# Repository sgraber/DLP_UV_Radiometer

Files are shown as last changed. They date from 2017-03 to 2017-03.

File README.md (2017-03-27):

# DLP_UV_Radiometer

This is a very simple, low cost, bare bones DLP UV Radiometer that measures the UV output of a DLP projector in mW/cm^2.  It is a useful tool for any DLP UV resin printer as it helps by measuring the UV output and by knowing your UV output and the Critical Energy required to properly cure a UV resin, the end user can calculate how many seconds exposure he or she will need.

MakerJuice MakerJuice Labs

I developed this with the initial intent to use it to characterize [MakerJuice UV Resins](http://www.makerjuice.com/) and decided it might be prudent to allow others to build this too and expand on it.  If expanding on this project, please credit both MakerJuice Labs and myself.  :)

Many UV resin manufacturers supply the Critical Energy required to properly cure their resins at a given layer height.  This number is typically supplied in mJ/cm^2.  If the end user knows their DLP UV output in mW/cm^2, they can simply apply the following forumla to find out how many seconds exposure they will need for their particular setup:

Seconds Exposure = (mJ/cm^2) / (mW/cm^2)

Then simply set your layer height and exposure time and the end user should be in the ballpark (or closer) for their exposure time.

As written, the sensor is wired up to an Arduino Nano, which is in turn plugged into either a computer or a smartphone with a USB-OTG cable.  To use it, simply place the sensor at the appropriate distance from the DLP light source and either use the Ardino IDI serial terminal to obtain the output reading or plug it into your smartphone using a USB-OTG cable and run something like DroidTerm to view your results.

# Hookup Guide

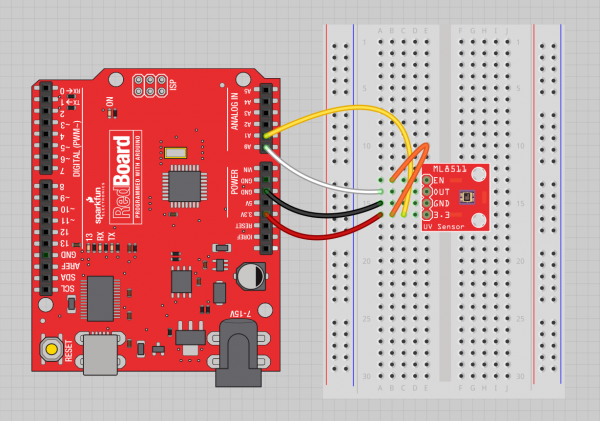
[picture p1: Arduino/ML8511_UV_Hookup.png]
Wiring Sparkfun Redboard and ML8511 Sensor


# Development Links

http://makerhive.proboards.com/thread/641/low-cost-uv-radiometer

https://learn.sparkfun.com/tutorials/ml8511-uv-sensor-hookup-guide

http://makerhive.proboards.com/thread/1045/help-circuit-schematic

https://goo.gl/photos/gHvPpna38RmeMD9JA

https://goo.gl/photos/hdz6ypwXF4V1uDZu9

https://goo.gl/photos/mLwZ4yQtefcNKiSG6

# License

CC-SA (see cc-sa-license.txt)

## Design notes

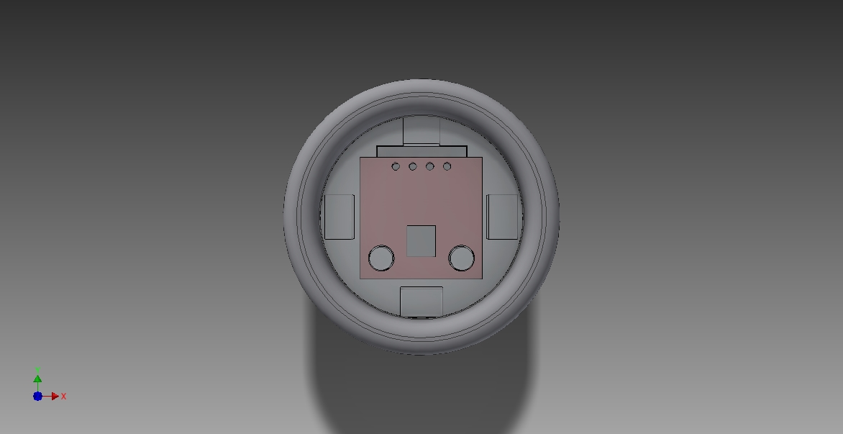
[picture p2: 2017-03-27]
STLs/UV Sensor2.jpg

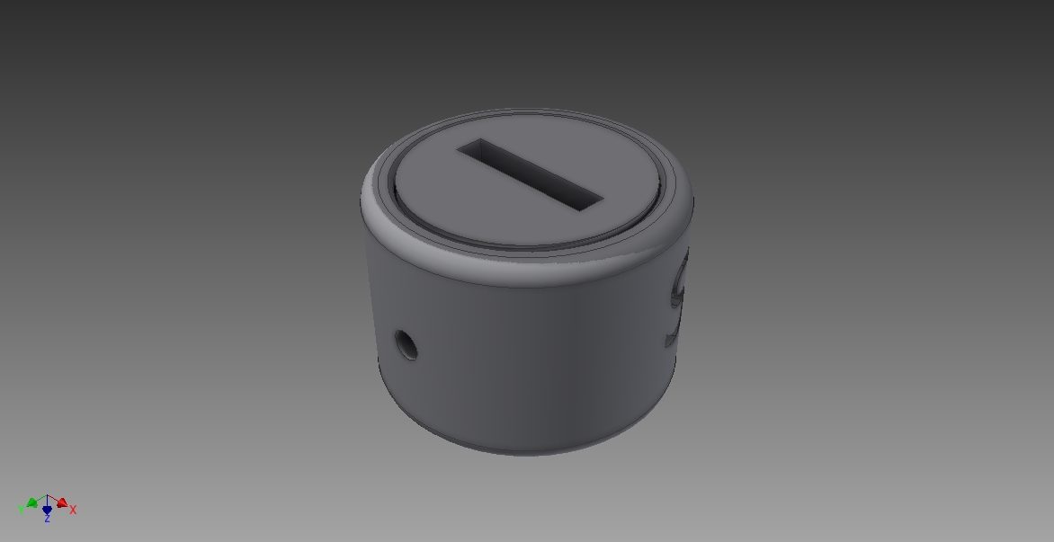
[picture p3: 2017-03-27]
STLs/UV Sensor3.jpg

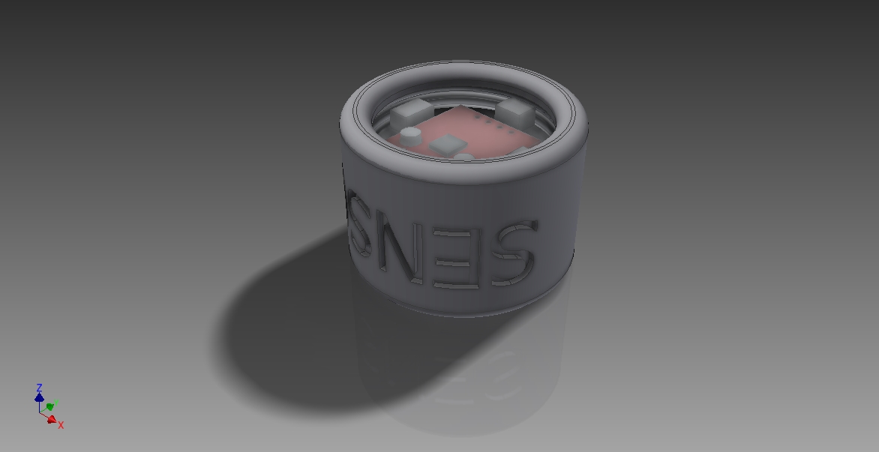
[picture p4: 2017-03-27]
STLs/UV Sensor.jpg

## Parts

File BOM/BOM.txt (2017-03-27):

Arduino Nano:  
	Any Nano clone will do.

UV Sensor:  SparkFun UV Sensor Breakout - ML8511
	Sparkfun:  https://www.sparkfun.com/products/12705
	Aliexpress:  Search for ML8511
	Ebay:  Search for ML8511

Telephone or Ethernet cable / wire:  18 inches

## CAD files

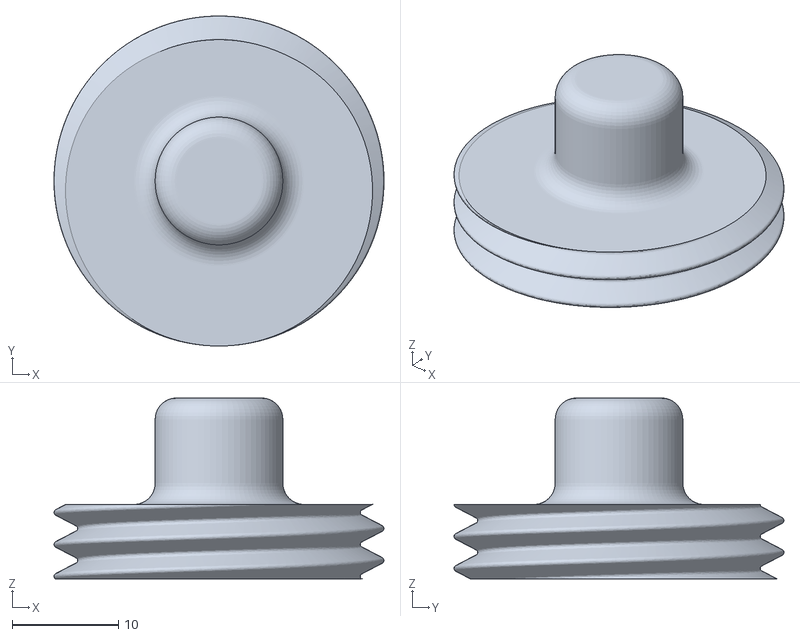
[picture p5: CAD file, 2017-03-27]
STLs/UV Sensor Cap.stl
31.0 x 31.0 x 17.0

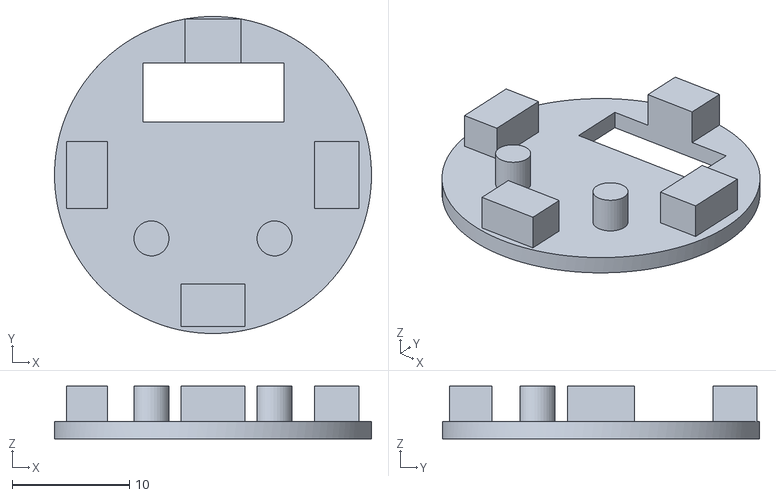
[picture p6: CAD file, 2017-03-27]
STLs/UV Sensor Plug.stl
27.0 x 27.0 x 4.50

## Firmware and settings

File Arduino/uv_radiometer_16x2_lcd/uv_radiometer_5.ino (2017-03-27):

/* 
 UV Radiometer for UV SLA Resins based on DLP Projectors
 By Shane Graber
 Vitrify3D LLC
 Date: August 28, 2014 
 
 This sensor detects 280-390nm light most effectively, but does absorb out to 
 ~450nm, similar to many photoinitiators used for UV SLA resins. Handy for 
 dialing in DLP projector-based SLA printers.
*/

// Library for calculating moving averages based on Gaussian smoothing and are
// required for the GaussianAverage function
// download from:
// https://github.com/ivanseidel/LinkedList
// https://github.com/ivanseidel/Gaussian
#include <LinkedList.h>
#include <Gaussian.h>
#include <GaussianAverage.h>

// NOTE: i tried moving averages before the above GaussianAverage class,
// and while my readings were relatively stable, the readings were VERY
// slow to change due to all the smoothing going on. The code was REALLY
// nasty too. GaussianAverage is much Much MUch MUCh MUCH faster and easier
// to implement.

// LCD library and definition
#include <LiquidCrystal.h>
LiquidCrystal lcd(12, 11, 5, 4, 3, 2);

//Hardware pin definitions for UV breakout board
int UVOUT = A0 ; //Output from the sensor
int REF_3V3 = A1 ; //3.3V power on the Arduino board

byte pos = 2;  // lcd position of the uv reading

// running averages for our sensor and define containers for them
// picked these values through trial and error!
#define num 50
GaussianAverage runningAverage(num);
GaussianAverage refAverage(num/10);
GaussianAverage uvIrradianceAverage(num/2);

// variable 'm' to slow down LCD updates in our loop()
#define m 50
byte n = m;

// git'er goin'
void setup() {
  
  // LCD assignments
  lcd.begin(8, 2);
  lcd.setCursor(0, 0);
  lcd.print("         ");
  lcd.setCursor(0, 1);
  lcd.print(" mW/cm2");
  
  // set our pins for the UV sensor
  pinMode(UVOUT, INPUT);
  pinMode(REF_3V3, INPUT);
  
  // populate the array with data initially
  for (byte foo = 0; foo < num*5; foo++) {
    runningAverage.add( Gaussian(analogRead(UVOUT), 1) );
    delay(10); // slow it down a bit; DO NOT CHANGE. you will have a bad time
  }
  
  // clear the numeric display area
  delay(500);
  lcd.setCursor(0, 0);
  lcd.print("         ");
  delay(500);
}

// weeeeeeeeeeeee a loop the loop!
void loop() {
  
  // add data to our gaussian averages
  // specifying ", 1" in the .add function is very important as it 
  // restricts the bell curve
  // NOTE: this loop is REQUIRED for our final UV output reading 
  // stability. without it, values range +/- 0.8 mW/cm^2
  // with it, values range +/- 0.1 mW/cm^2
  for (byte foo = 0; foo < num; foo++) {
    runningAverage.add( Gaussian(analogRead(UVOUT), 1) );
    refAverage.add( Gaussian(analogRead(REF_3V3), 1) );
    delay(1);  // slow down our reading a tiny bit
  }

  // find the gaussian average for both the UV sensor and our 3.3V reference   
  // 3.3V reference doesn't fluctuate much, but hey, why not...
  float uvLevel = runningAverage.process().mean;
  float refLevel = refAverage.process().mean;

  // calculate our UV sensor output voltage
  // and map it to a given UV irradiance in mW/cm^2
  // see: https://cdn.sparkfun.com/datasheets/Sensors/LightImaging/ML8511_3-8-13.pdf
  float outputVoltage = 3.30 / refLevel * uvLevel;
  float uvIntensity = mapfloat(outputVoltage, 1.00, 2.80, 0.00, 15.00);
  
  // use another gaussian average for our final output reading stability
  uvIrradianceAverage.add( Gaussian(uvIntensity, 2));
  float uvIrradiance = uvIrradianceAverage.process().mean;
  
  // only update the LCD display every N times through the loop
  // otherwise it flickers too much
  if (n == m) {
    n = 0;
    lcd.setCursor(0, 0);
    lcd.print("         ");
    if (uvIrradiance < 10.0) {
      pos = 3;
    } else {
      pos = 2;
    }
    lcd.setCursor(pos, 0);
    lcd.print(abs(uvIrradiance), 1);
  } else {
    n = n + 1;
  }
}

//The Arduino Map function but for floats
//From: http://forum.arduino.cc/index.php?topic=3922.0
float mapfloat(float x, float in_min, float in_max, float out_min, float out_max) {
  return (x - in_min) * (out_max - out_min) / (in_max - in_min) + out_min;
}

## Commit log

2017-03-27 Initial commit.
    [LittleRP - Acer X1240 UV Intensity Data.xlsx, UV Sensor Cap.stl, UV Sensor Plug.stl]
2017-03-27 updated bom with uv sensor info
2017-03-27 added wiring diagram.
